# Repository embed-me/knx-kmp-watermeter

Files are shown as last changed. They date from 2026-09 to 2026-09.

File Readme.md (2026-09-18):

# KNX KMP Watermeter



KNX TP1 interface for Kamstrup water/heat meters via the KMP (Kamstrup Meter Protocol). Reads meter data (volume, flow, temperature, battery life) and exposes it on the KNX bus.

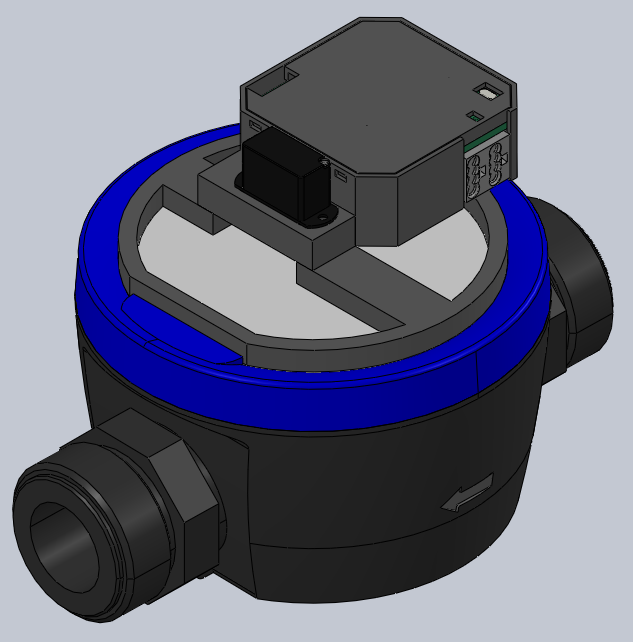
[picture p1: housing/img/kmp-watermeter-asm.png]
KMP Watermeter assembly


## Overview

The device is built around an RP2040 (Raspberry Pi Pico) coupled to the KNX bus via an NCN5130-based BCU. It polls the meter over its optical interface using the KMP protocol and publishes the readings as KNX group objects: 

- **Volume** (m³)
- **Flow** (l/h)
- **Temperature** (°C)
- **Battery life** (days)

Registers can be enabled/disabled individually and polled on a configurable crontab-style schedule.

## Project Structure

| Directory | Description | Documentation |
|---|---|---|
| `firmware/` | RP2040 firmware (PlatformIO, C++) | [Readme.md](firmware/Readme.md) |
| `hardware/` | PCB design (Altium Designer) | [Readme.md](hardware/Readme.md) |
| `housing/` | 3D-printable enclosure (SOLIDWORKS) | [Readme.md](housing/Readme.md) |
| `software/` | KNX ETS product database source | [Readme.md](software/Readme.md) |

## Firmware

Custom firmware for the RP2040 that implements the KMP protocol stack over UART to communicate with Kamstrup Multical 601/801 meters. Data is published via the KNX TP1 bus using the thelsing/knx library with an NCN5130-based BCU. Meters are polled via a servo-actuated wake-up mechanism.

See [firmware/Readme.md](firmware/Readme.md) for build, flash, and test instructions.

## Hardware

Custom 2-layer PCB combining an RP2040 MCU with an NCN5130 BCU (NanoBCU-based) for KNX TP1 bus coupling. Includes a servo driver for meter wake-up and an IR optical transceiver for KMP communication.

See [hardware/Readme.md](hardware/Readme.md) for the project structure and production package.

## Housing

Flush-mount 3D-printable enclosure consisting of four printed parts, designed for standard installation boxes.

See [housing/Readme.md](housing/Readme.md) for the model files and ready-to-print STL exports.

## ETS Configuration

KNX product database for ETS (tested with ETS 6.6). The device exposes group objects for volume, flow, temperature, and battery life, with configurable polling intervals and per-register enable/disable.

See [software/Readme.md](software/Readme.md) for group objects, parameters, and regeneration instructions.

## License

MIT — see [LICENSE](LICENSE).

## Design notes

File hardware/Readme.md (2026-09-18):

# Hardware — KMP Watermeter PCB

PCB combining an RP2040 MCU (Raspberry Pi Pico) with an NCN5130 BCU (NanoBCU-based) for KNX TP1 bus coupling. It uses a servo driver for water meter wake-up, driving a NEEBRC 2g Micro Servo.

The board is designed as a 2-layer PCB in Altium Designer.

The NanoBCU and the UP board are available from [muster.ing-dom.de](https://muster.ing-dom.de/).

## Project Structure

| Directory | Contents |
|---|---|
| [project/](project/) | Altium Designer project: schematic (3 sheets), PCB, BOM, and custom component libraries |
| [production_package/](production_package/) | Ready-to-order Gerber files and drill data |
| [Design Rules/](Design%20Rules/) | JLCPCB design rule files (2-layer, 1 oz / 2 oz copper) |

The schematic is split into three sheets: the main sheet (MCU sockets, servo header, power supply), plus dedicated [Transmitter](project/Transmitter.SchDoc) and [Receiver](project/Receiver.SchDoc) sheets for the IR optical transceiver used for KMP communication.

## Production Package

Ready-to-order PCB files are available in the [production package](production_package/).

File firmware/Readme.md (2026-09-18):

# KNX KMP Watermeter — Firmware

RP2040 firmware implementing the Kamstrup Meter Protocol (KMP) over UART to read data from Kamstrup Multical 601/801 water/heat meters and publish it on the KNX TP1 bus.

## Setup

```bash
pip install platformio
```

## Build

```bash
pio run -e release
```

Flash `.pio/build/release/firmware.uf2` via UF2 bootloader (hold BOOTSEL, press RESET, copy UF2 to mounted drive).

## Unit Tests

```bash
pio test -e test
```

## Static Code Analysis

```bash
sudo apt-get install -y cppcheck
pio check -e check
```

## Protocol Reference

- [Kamstrup.md](Kamstrup.md) — KMP protocol description (extracted from Kamstrup document 5512-447)

## Architecture

The firmware implements a layered KMP protocol stack:

| Layer | Responsibility |
|---|---|
| `PhysicalLayer` | UART framing, byte-stuffing, start/stop detection |
| `DataLinkLayer` | Destination addressing, CRC-16/CCITT verification |
| `ApplicationLayer` | Command dispatch (GetSerialNo, GetRegister), response routing |

Devices polled via servo-actuated wake-up mechanism. See `src/application/WatermeterApp.cpp` for the main polling loop.

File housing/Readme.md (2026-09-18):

# Housing — KMP Watermeter Enclosure

3D-printable housing for the KMP Watermeter - designed to be robust and compact.

## Assembly

The animation below shows how the individual parts come together into the final assembly:

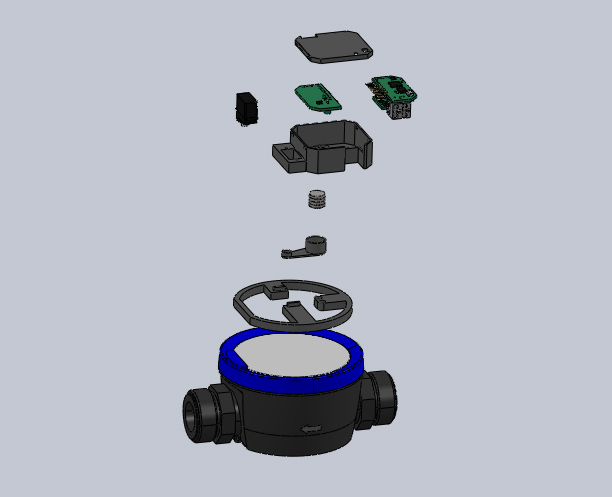
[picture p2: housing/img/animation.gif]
Housing assembly animation


## Model

The housing is modeled in SOLIDWORKS and consists of four parts:

| Part | File |
|---|---|
| Housing | [Housing.SLDPRT](parts/Housing.SLDPRT) |
| Cover | [Cover.SLDPRT](parts/Cover.SLDPRT) |
| Servo Arm | [Servo Arm.SLDPRT](parts/Servo%20Arm.SLDPRT) |
| Fixture | [Fixture.SLDPRT](parts/Fixture.SLDPRT) |

The part files are available in the [parts](parts/) directory. The complete assembly combining all parts and PCBs is available in the [assembly](assembly/) directory.

The Servo Arm is designed for the [NEEBRC 2g Micro Servo](https://de.aliexpress.com/item/1005010177333036.html), which actuates the water meter wake-up mechanism.

## Exported STL Files for Printing

If you'd like to print the housing as-is, the ready-to-use STL files are available in the [print_package](print_package/) directory.

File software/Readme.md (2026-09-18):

# Software — KNX ETS Product Database

ETS product database for the KNX KMP Watermeter, tested with **ETS 6.6**.

## Quick Start

If you do not need to modify the product database, simply load the [existing product database](productdatabase/) into ETS and use it as any other vendor product.

## Group Objects

| No. | Name | Function | DPT |
|-----|---|---|-----|
| 1 | Linked | Connection state to the meter, updated on every poll | DPT_State |
| 2 | Flow | Current water flow | DPT_Value_Volume_Flow |
| 3 | Volume | Total volume | DPT_Value_Volume |
| 4 | Temperature | Water temperature | DPT_Value_Temp |
| 5 | Battery Life | Remaining battery life in days | DPT_Value_2_Ucount |
| 6 | Time | Device RTC time sync input | DPT_Time (10.001) |
| 7 | Date | Device RTC date sync input | DPT_Date (11.001) |

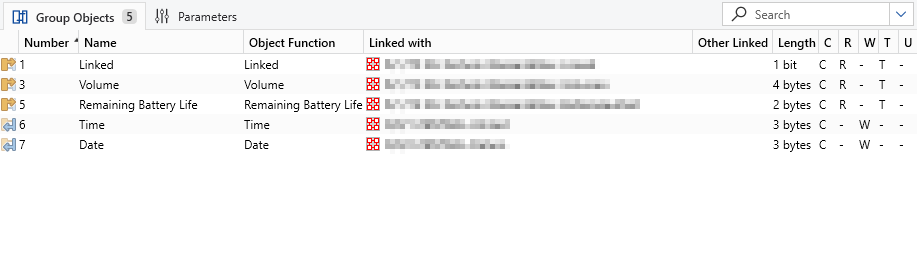
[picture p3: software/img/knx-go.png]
Group objects in ETS


## ETS Parameters

| Parameter | Type | Description |
|---|---|---|
| Polling Interval | Text (16 chars) | Crontab-style schedule for register polling (see below) |
| Volume | 1-bit | Enable/disable volume register read |
| Flow | 1-bit | Enable/disable flow register read |
| Temperature | 1-bit | Enable/disable temperature register read |
| Battery Life | 1-bit | Enable/disable battery life register read |

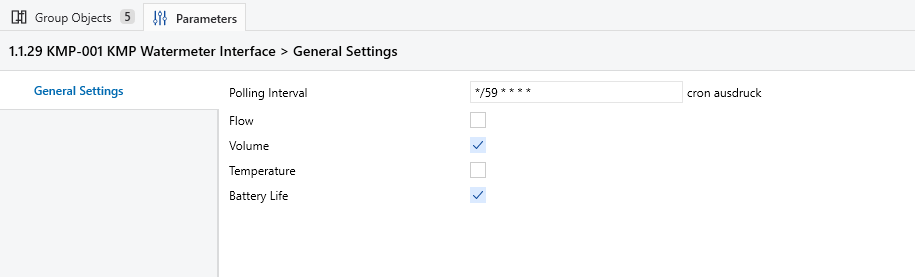
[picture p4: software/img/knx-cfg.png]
ETS parameters


### Polling Interval Format

Standard crontab syntax with five fields: minute (0–59), hour (0–23), day of month (1–31), month (1–12), day of week (1–7, Sunday = 7). Each field supports `*`, step values (`*/15`), ranges (`9-17`), and comma-separated lists (`5,10,15`).

Examples:
- `*/15 * * * *` — every 15 minutes
- `0 9-17 * * 1-5` — hourly between 9:00 and 17:00 on weekdays

The schedule is evaluated against the device RTC, which is synchronized via the Time (6) and Date (7) group objects.

## KMP Registers Polled

| Register ID | Name | Unit |
|---|---|---|
| `0x0044` | Volume | m³/l |
| `0x004A` | Flow | l/h |
| `0x0124` | Temperature | °C |
| `0x0246` | Battery Life | days |

## Tools

The product database is created with **[Kaenx-Creator](https://github.com/OpenKNX/Kaenx-Creator)**.

### Recommended Version

Kaenx-Creator is under active development. Use **[v1.8.4](https://github.com/OpenKNX/Kaenx-Creator/tree/v1.8.4)** for compatibility.

- **Binary Download**: [Kaenx Creator v1.8.4](https://github.com/OpenKNX/Kaenx-Creator/releases/download/v1.8.4/Kaenx.Creator.Binaries.zip)
- **MD5 Hash**: `9aeb971f7844eeafb54341031f3e4ef8`

## Regeneration

To modify or recreate the product database:

1. Open `kmp-watermeter.ae-manu` in Kaenx-Creator.
2. Make changes and increase the version number.
3. Re-deploy the database.

Generated outputs include:

- **`knxprod.h`** — Move this file to `firmware/src/drivers/knx/data/`.

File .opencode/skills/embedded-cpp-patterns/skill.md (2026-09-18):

# Embedded C++ Patterns (SOLID & DRY)

Guidelines for embedded firmware design applied in this repo.

## SOLID in practice

| Principle | Application in this repo |
|---|---|
| **S**ingle Responsibility | Each class does one thing: `CommandQueue` queues commands, `CRC` computes checksums, `PhysicalLayer` handles UART framing |
| **O**pen/Closed | Interfaces (`IKnxDriver`, `IGpioDriver`, `ITimer`) are open for extension via new implementations, closed for modification |
| **L**iskov Substitution | All interface implementations are substitutable — `ArduinoTimer` can be swapped with `MockTimer` in tests |
| **I**nterface Segregation | `IDriverFactory` is composed of small segregated interfaces (`IGpioDriverFactory`, `IKnxDriverFactory`, etc.) |
| **D**ependency Inversion | High-level code (`WatermeterApp`) depends on abstractions (`IApplicationLayer`, `ITimer`), not concretions |

## OOP Principles

| Principle | Application |
|---|---|
| **Encapsulation** | Each driver interface (`IGpioDriver`, `ITimer`) hides platform internals behind a clean API. State and config are private; only the interface is exposed. |
| **Polymorphism** | Interfaces enable multiple implementations — `ArduinoTimer` (real hardware) and `MockTimer` (test) both implement `ITimer`. |
| **Inheritance** | Class hierarchies follow interface contracts. `ArduinoGpioDriver : IGpioDriver`, `ArduinoLogger : ILogger`. Interfaces are pure virtual with `= 0`. |
| **Composition > Inheritance** | `WatermeterApp` *has-a* `CommandQueue`, *has-a* `ITimer`, *has-a* `IApplicationLayer`. Favor composing small interfaces over deep class hierarchies. |

## DRY — Don't Repeat Yourself

- Factor hardware platform code behind interfaces in `firmware/src/drivers/`
- Reuse `CommandQueue`, `CRC`, `ByteStuff` across commands and layers
- If you write the same logic twice, extract it into `firmware/src/utils/`

## Embedded-specific patterns

| Pattern | Where | Why |
|---|---|---|
| **Interface + Impl** | `drivers/*/I*.hpp` + `arduino/*.cpp` | Decouple from Arduino/Pico SDK; enables native testing |
| **Dependency Injection** | Constructor args (e.g. `WatermeterWakeupDriver(motion, cfg, timer)`) | Testable without hardware |
| **RAII** | `shared_ptr` ownership throughout | Automatic cleanup on resource-constrained MCU |
| **Factory** | `ArduinoDriverFactory`, `ArduinoTimerFactory` | Centralized creation of platform-specific objects |
| **Strategy** | `ISchedulerStrategy` / `SimpleScheduler` | Pluggable scheduling behavior |
| **Layered Protocol** | `PhysicalLayer` → `DataLinkLayer` → `ApplicationLayer` | OSI-inspired separation of concerns |
| **Observer** | Listener callbacks in transport layers | Decouple senders from receivers |

## Code style rules

1. Pure virtual interfaces get `I` prefix: `ITimer`, `IGpioDriver`
2. Config structs are plain `struct`s with aggregate init
3. No exceptions (RTTI only for KNX stack); errors flow through `CommandResult`
4. Avoid dynamic allocation in hot paths; pre-allocate in `setup()`
5. Logging is disabled in release (`-DKNX_KMP_WATERMETER_DISABLE_LOGGING`)

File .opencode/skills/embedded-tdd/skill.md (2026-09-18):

# Embedded TDD (Red-Green-Refactor)

Test-Driven Development for embedded C++ firmware using GoogleTest on native host.

## Workflow

### 1. RED — Write a failing test first
- Add a new test suite under `firmware/test/test_<component>/`
- Each suite needs a `test_main.cpp` and `test_<component>.cpp`
- Include the unit-under-test's `.cpp` directly (native compilation needs it)
- Use `TEST()` or `TEST_F()` from GoogleTest

```cpp
// test/test_foo/test_foo.cpp
#include <gtest/gtest.h>
#include "src/path/to/Foo.cpp"

TEST(FooTest, DoesThing) {
    Foo foo;
    EXPECT_EQ(foo.doThing(), expected);
}
```

### 2. GREEN — Make it compile and pass
- Implement the minimum code in the production source
- For hardware dependencies, use mocks from `test/mocks/`:
  ```cpp
  auto mockTimer = std::make_shared<MockTimer>();
  auto driver = WatermeterWakeupDriver(motion, cfg, mockTimer);
  ```
- For hardware headers unavailable on host, use stubs in `test/stubs/`
- Run: `pio test -e test`

### 3. REFACTOR — Clean up while keeping green
- Apply SOLID and OOP principles, remove duplication, rename for clarity
- Do NOT change behavior
- Re-run tests to confirm

## Test infrastructure conventions

| Resource | Location | Purpose |
|---|---|---|
| Tests | `firmware/test/test_*/` | One directory per component |
| Mocks | `firmware/test/mocks/` | Hand-rolled mock classes (no mocking framework) |
| Stubs | `firmware/test/stubs/` | Platform headers unavailable on host (e.g. `pico/time.h`) |
| Main | `firmware/test/test_*/test_main.cpp` | GoogleTest entry point (`RUN_ALL_TESTS`) |

## Writing mocks

Follow the existing pattern in `test/mocks/`:

```cpp
struct MockFoo : public IFoo {
    bool doThingCalled = false;
    int doThingResult = 42;

    int doThing() override {
        doThingCalled = true;
        return doThingResult;
    }
};
```

Build commands are in [firmware/Readme.md](../../../firmware/Readme.md).

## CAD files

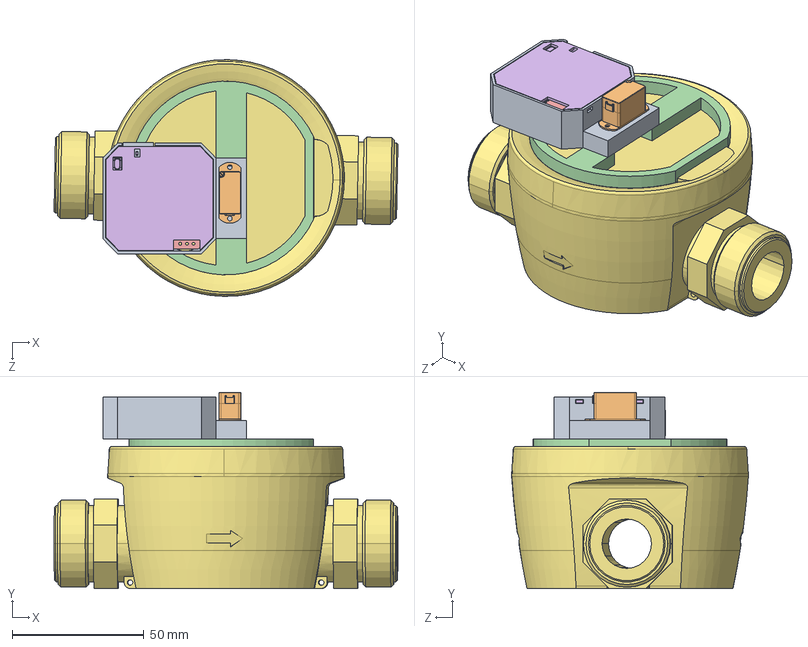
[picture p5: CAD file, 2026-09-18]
housing/assembly/Watermeter-ASM.SLDASM
130.5 x 74.5 x 89.8 mm
Housing
Servo Motor Mini 2g
Servo Arm
Fixture
Leader^6685220592_Q1_PCB KMP-Watermeter_Watermeter-ASM x 3
Extruded^6472411584_R7_PCB KMP-Watermeter_Watermeter-ASM
Extruded-0^6472401024_R7_PCB KMP-Watermeter_Watermeter-ASM x 2
Extruded^6472411584_R8_PCB KMP-Watermeter_Watermeter-ASM
Extruded-0^6472401024_R8_PCB KMP-Watermeter_Watermeter-ASM x 2
Extruded^6472411584_R6_PCB KMP-Watermeter_Watermeter-ASM
Extruded-0^6472401024_R6_PCB KMP-Watermeter_Watermeter-ASM x 2
Extruded-1^6472403024_C3_PCB KMP-Watermeter_Watermeter-ASM x 2
Extruded-2^6472401344_C3_PCB KMP-Watermeter_Watermeter-ASM
6488013344^LED-RX-1_PCB KMP-Watermeter_Watermeter-ASM
6488013344^LED-TX-1_PCB KMP-Watermeter_Watermeter-ASM
Extruded^6472411584_R5_PCB KMP-Watermeter_Watermeter-ASM
Extruded-0^6472401024_R5_PCB KMP-Watermeter_Watermeter-ASM x 2
Extruded^6472411584_R1_PCB KMP-Watermeter_Watermeter-ASM
Extruded-0^6472401024_R1_PCB KMP-Watermeter_Watermeter-ASM x 2
Extruded^6472411584_R2_PCB KMP-Watermeter_Watermeter-ASM
Extruded-0^6472401024_R2_PCB KMP-Watermeter_Watermeter-ASM x 2
Extruded^6472411584_R3_PCB KMP-Watermeter_Watermeter-ASM
Extruded-0^6472401024_R3_PCB KMP-Watermeter_Watermeter-ASM x 2
Extruded^6472411584_R4_PCB KMP-Watermeter_Watermeter-ASM
Extruded-0^6472401024_R4_PCB KMP-Watermeter_Watermeter-ASM x 2
Extruded-3^6472401664_C1_PCB KMP-Watermeter_Watermeter-ASM x 2
Extruded-4^6472401184_C1_PCB KMP-Watermeter_Watermeter-ASM
Extruded-3^6472401664_C2_PCB KMP-Watermeter_Watermeter-ASM x 2
Extruded-4^6472401184_C2_PCB KMP-Watermeter_Watermeter-ASM
pinheader_20pin_127mm_pitch^P1_PCB KMP-Watermeter_Watermeter-ASM
Copy of Pcb_d6bd^PCB UP1-Controller2040_V00.02
Copy of Copy of J102_PinHeader_1x20_P127mm_Horizontal_60EE9F63^PCB UP1-Controller2040_V00.02
Copy of R111_R_0603_1608Metric_6205EFC4^PCB UP1-Controller2040_V00.02
Copy of R112_R_0603_1608Metric_6205EFD5^PCB UP1-Controller2040_V00.02
Copy of GN100_NanoBCU_V00.10_wo_headers_60EECF29^PCB UP1-Controller2040_V00.02
Copy of GN100_PinHeader_1x07_P254mm_Vertical_SMD_Pin1Left_60EECF29[2]^PCB UP1-Controller2040_V00.02
Copy of U102_SOT_23_5_6205ACC4^PCB UP1-Controller2040_V00.02
Copy of U103_SOT_23_6_6205A775^PCB UP1-Controller2040_V00.02
Copy of J100__243-212_60AF9738^PCB UP1-Controller2040_V00.02
Copy of R114_R_0603_1608Metric_61113DD2^PCB UP1-Controller2040_V00.02
Copy of R113_R_0603_1608Metric_61113DC1^PCB UP1-Controller2040_V00.02
Copy of D100_D_SMA_60EECA5D^PCB UP1-Controller2040_V00.02
Copy of J101_PinHeader_1x08_P127mm_Vertical_60ECF3C0^PCB UP1-Controller2040_V00.02
Copy of R109_R_0603_1608Metric_60F57743^PCB UP1-Controller2040_V00.02
Copy of R110_R_0603_1608Metric_60F57732^PCB UP1-Controller2040_V00.02
Copy of R106_R_0402_1005Metric_60F519DA^PCB UP1-Controller2040_V00.02
Copy of U100_QFN-56-1EP_7x7mm_Pitch0.4mm_60ECE89B^PCB UP1-Controller2040_V00.02
Copy of R115_R_0603_1608Metric_60ECF916^PCB UP1-Controller2040_V00.02
Copy of R116_R_0603_1608Metric_60B1282C^PCB UP1-Controller2040_V00.02
Copy of U101_SSOP_8_525x524mm_P127mm_60EDBF3D^PCB UP1-Controller2040_V00.02
Copy of Y100_Crystal_SMD_3225-4Pin_3.2x2.5mm_60EEB131^PCB UP1-Controller2040_V00.02
Copy of SW100_SKRPACE010_v4_60ED873A^PCB UP1-Controller2040_V00.02
Copy of R105_C_0402_1005Metric_60ECE7EE^PCB UP1-Controller2040_V00.02
Copy of R108_C_0402_1005Metric_60ECE7DF^PCB UP1-Controller2040_V00.02
Copy of R107_C_0402_1005Metric_60ECE7D0^PCB UP1-Controller2040_V00.02
Copy of R102_C_0402_1005Metric_60ECE7C1^PCB UP1-Controller2040_V00.02
Copy of R103_C_0402_1005Metric_60ECE7B2^PCB UP1-Controller2040_V00.02
Copy of R104_C_0402_1005Metric_60ECE7A3^PCB UP1-Controller2040_V00.02
Copy of R101_R_0402_1005Metric_60ECE794^PCB UP1-Controller2040_V00.02
Copy of D101_LED_0603_1608Metric_60EEBCB9^PCB UP1-Controller2040_V00.02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

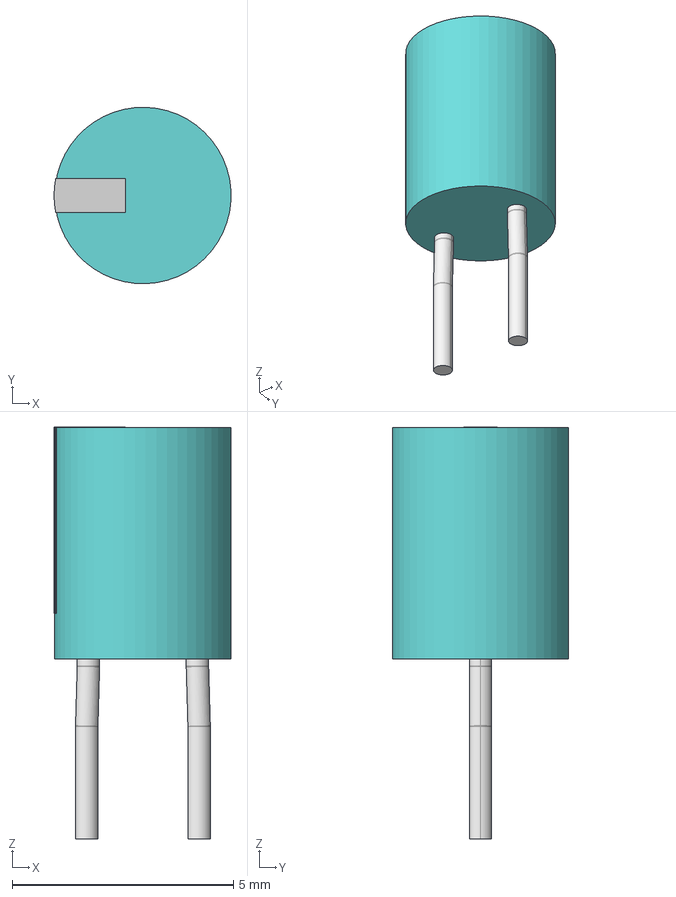
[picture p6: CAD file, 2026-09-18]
hardware/project/Components/HIR204C/LED_RADIAL_HIR204C.step
4.00 x 3.99 x 9.31 mm

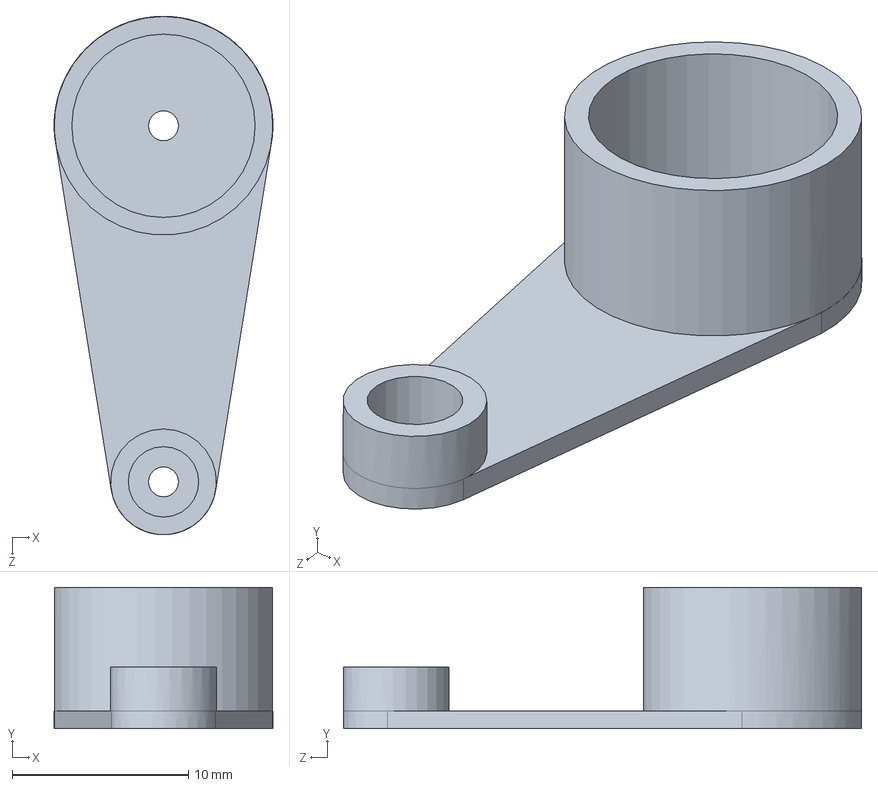
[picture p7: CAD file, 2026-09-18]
housing/parts/Servo Arm.SLDPRT
12.4 x 8.00 x 29.4 mm

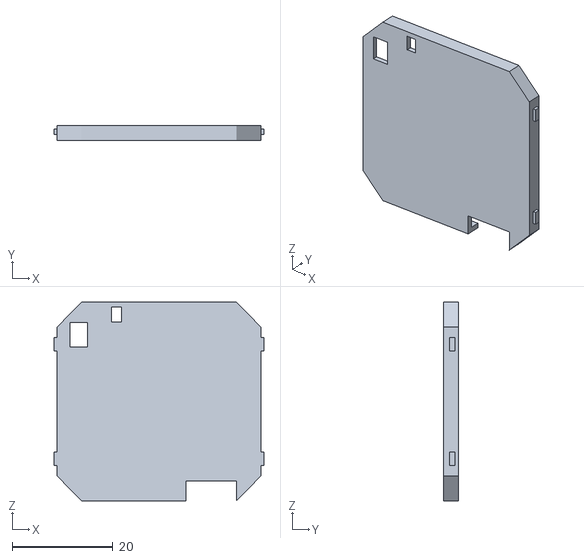
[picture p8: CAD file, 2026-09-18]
housing/print_package/Cover.STL
41.7 x 3.00 x 39.5

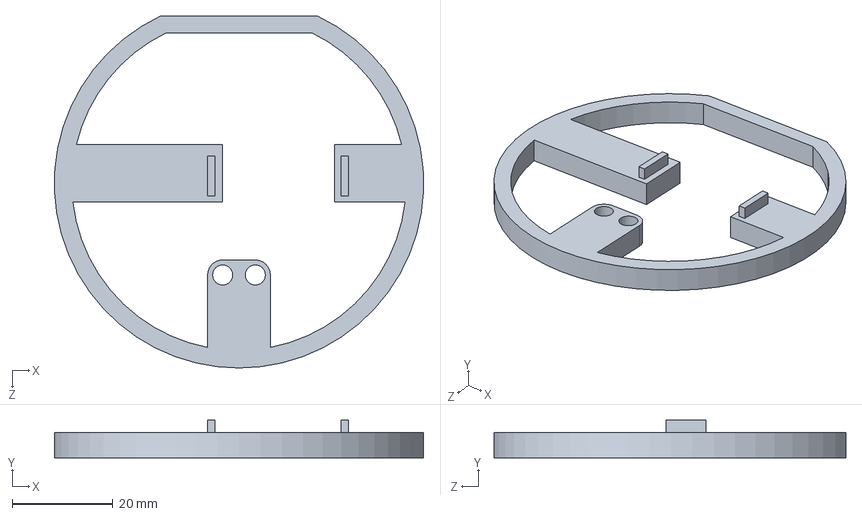
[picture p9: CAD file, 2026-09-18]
housing/parts/Fixture.SLDPRT
73.4 x 7.50 x 70.0 mm

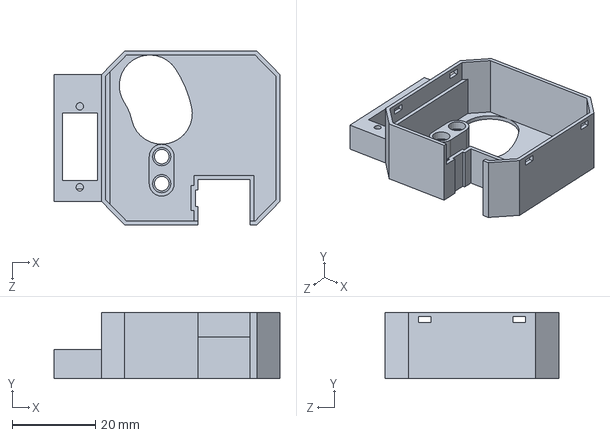
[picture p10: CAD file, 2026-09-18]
housing/parts/Housing.SLDPRT
54.5 x 16.0 x 42.0 mm

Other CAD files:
housing/print_package/Fixture.STL
housing/print_package/Servo Arm.STL
housing/parts/Cover.SLDPRT
housing/print_package/Housing.STL

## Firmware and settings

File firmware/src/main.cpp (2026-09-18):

#include <memory>

#include "drivers/ArduinoDriverFactory.hpp"
#include "drivers/motion/MotionConfig.hpp"

#include "drivers/logger/Logger.hpp"
#include "drivers/logger/ILogger.hpp"

#include "drivers/gpio/IGpioDriver.hpp"

#include "drivers/knx/IKnxDriver.hpp"

#include "drivers/watchdog/IWatchdogDriver.hpp"

#include "drivers/uart/IUartDriver.hpp"

#include "drivers/watermeter/kamstrup/utils/CommandQueueConfig.hpp"

#include "utils/scheduler/Scheduler.hpp"
#include "utils/scheduler/strategy/ISchedulerStrategy.hpp"
#include "utils/scheduler/strategy/simple/SimpleScheduler.hpp"

#include "application/WatermeterApp.hpp"

/* GPIOs */
struct drivers::gpio::GpioConfig knxProgButton = {
    .pin = 7,
    .sensitivity = drivers::gpio::GPIO_SENSITIVITY::INTERRUPT_CHANGE,
    .direction = drivers::gpio::GPIO_DIRECTION::DIRECTION_INPUT,
    .pull = drivers::gpio::GPIO_PULL::PULL_HIGH
};

struct drivers::gpio::GpioConfig knxProgLed = {
    .pin = 6,
    .sensitivity = drivers::gpio::GPIO_SENSITIVITY::ACTIVE_HIGH,
    .direction = drivers::gpio::GPIO_DIRECTION::DIRECTION_OUTPUT,
    .pull = drivers::gpio::GPIO_PULL::PULL_NONE
};

struct drivers::uart::UartConfig kmpUartCfg = {
    .baud = 1200,
    .dataBits = 8,
    .parity = 0,
    .stopBits = 2,
    .txPin = 20,
    .rxPin = 21
};

drivers::motion::MotionConfig wakeupMotionCfg = { 
    .pin = 13,
    .minPulseWidth = 500,
    .maxPulseWidth = 2500,
    .wakeupAngle = 114,
    .sleepAngle = 90,
    .settleDelayUs = 5000000
};

drivers::watermeter::kamstrup::transport::CommandQueueConfig kmpQueueCfg = {
    .commandTimeoutUs = 1600000
};

std::shared_ptr<drivers::IDriverFactory> driverFactory =
    std::make_shared<drivers::ArduinoDriverFactory>();
#ifdef KNX_KMP_WATERMETER_DISABLE_LOGGING
    std::shared_ptr<drivers::logger::ILogger> logger = nullptr;
#else
    std::shared_ptr<drivers::logger::ILogger> logger = driverFactory->getLoggerDriver();
#endif
std::shared_ptr<drivers::gpio::IGpioDriver> gpio = driverFactory->getGpioDriver();
std::shared_ptr<drivers::knx::IKnxDriver> knx = driverFactory->getKnxDriver();
std::shared_ptr<drivers::watchdog::IWatchdogDriver> watchdog = driverFactory->getWatchdogDriver();
std::shared_ptr<drivers::uart::IUartDriver> kmpUart = driverFactory->getUartDriver();
std::shared_ptr<drivers::timer::ITimerDriverFactory> timerFactory = driverFactory->getTimerDriverFactory();

/* Utilities */
std::shared_ptr<utils::ISchedulerStrategy> schedulerStrategy = std::make_shared<utils::SimpleScheduler>();
std::shared_ptr<utils::Scheduler> scheduler = std::make_shared<utils::Scheduler>(schedulerStrategy);

#define WDT_TIMEOUT_MS 8000
#define PROG_BTN_PRESS_MIN_MILLIS 50
#define PROG_BTN_PRESS_MAX_MILLIS 500

void buttonPressHandler(void *arg) 
{
    static uint32_t lastEvent = 0;
    static uint32_t lastPressed = 0;

    uint32_t diff = millis() - lastEvent;

    if (diff >= PROG_BTN_PRESS_MIN_MILLIS && diff <= PROG_BTN_PRESS_MAX_MILLIS)
    {
        if (millis() - lastPressed > 200)
        {
            knx->toggleProgMode();
            lastPressed = millis();
        }
    }

    lastEvent = millis();
}

void buttonInterrupt()
{
    utils::Scheduler::schedule(buttonPressHandler);
}

std::shared_ptr<application::WatermeterApp> watermeterApp = nullptr;

/* Core 0 */
void setup() {
    drivers::logger::Logger::setLogger(logger);
    drivers::logger::Logger::getLogger()->init(drivers::logger::LOGLEVEL::LOGLEVEL_TRACE, true);

    if (watchdog->wasRebootedByWatchdog()) {
        logWarning("System rebooted by watchdog");
    }

    watchdog->enable(WDT_TIMEOUT_MS);

    gpio->setConfig(knxProgLed);
    gpio->setConfig(knxProgButton);
    gpio->setupInterruptHandler(knxProgButton, buttonInterrupt);
    knx->setProgmodeChangeCallback([](bool val) {
        gpio->writeValue(knxProgLed, val);
    });

    bool stackConfigured = knx->init();

    if (stackConfigured) {
        std::string version = knx->getApplicationVersion();
        logInfo("Application Version: " + version);

        auto& knxConfig = knx->getKnxConfig();
        watermeterApp = std::make_shared<application::WatermeterApp>();

        auto motion = driverFactory->getMotionDriver();
        motion->setConfig(wakeupMotionCfg);
        auto wakeupDriver = driverFactory->getWatermeterWakeupDriver(motion, wakeupMotionCfg);
        auto rtcDriver = driverFactory->getRtcDriver();

        watermeterApp->init(kmpUart, kmpUartCfg, knxConfig, kmpQueueCfg, wakeupDriver, timerFactory, rtcDriver);
    } else {
        logWarning("KNX Stack initialization failed");
    }
}

void loop() {
    watchdog->feed();
    watermeterApp->process();
    scheduler->process();
    knx->loop();
}

/* Core 1 */
// void setup1() {
// }

// void loop1() {
// }

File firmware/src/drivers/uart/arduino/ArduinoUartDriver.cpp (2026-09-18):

#include "ArduinoUartDriver.hpp"
#include "src/drivers/logger/Logger.hpp"
#include <Arduino.h>
#include <HardwareSerial.h>

using namespace drivers::logger;

namespace drivers::uart {

ArduinoUartDriver::ArduinoUartDriver()
{
}

bool ArduinoUartDriver::init(const UartConfig &config) 
{
    if (config.dataBits < 5 || config.dataBits > 8) {
        logError("ArduinoUartDriver: invalid dataBits %d", config.dataBits);
        return false;
    }

    if (config.stopBits < 1 || config.stopBits > 2) {
        logError("ArduinoUartDriver: invalid stopBits %d", config.stopBits);
        return false;
    }

    if (config.parity > 2) {
        logError("ArduinoUartDriver: invalid parity %d", config.parity);
        return false;
    }

    // Use Arduino Serial2 (UART1) for KMP communication.
    // Serial1 (UART0) is already used by the KNX stack (KNX_SERIAL).
    if (config.txPin >= 0) {
        Serial2.setTX(config.txPin);
    }
    if (config.rxPin >= 0) {
        Serial2.setRX(config.rxPin);
    }

    int serialConfig = SERIAL_8N1;
    if (config.dataBits == 5) {
        serialConfig = (config.parity == 0) ? SERIAL_5N1 : (config.parity == 1) ? SERIAL_5O1 : SERIAL_5E1;
    } else if (config.dataBits == 6) {
        serialConfig = (config.parity == 0) ? SERIAL_6N1 : (config.parity == 1) ? SERIAL_6O1 : SERIAL_6E1;
    } else if (config.dataBits == 7) {
        serialConfig = (config.parity == 0) ? SERIAL_7N1 : (config.parity == 1) ? SERIAL_7O1 : SERIAL_7E1;
    } else if (config.dataBits == 8) {
        if (config.stopBits == 2) {
            serialConfig = (config.parity == 0) ? SERIAL_8N2 : (config.parity == 1) ? SERIAL_8O2 : SERIAL_8E2;
        } else {
            serialConfig = (config.parity == 0) ? SERIAL_8N1 : (config.parity == 1) ? SERIAL_8O1 : SERIAL_8E1;
        }
    }

    Serial2.begin(config.baud, serialConfig);
    logInfo("ArduinoUartDriver: initialized at %d baud (%d data bits, %d stop bits, tx=%d rx=%d)", config.baud, config.dataBits, config.stopBits, config.txPin, config.rxPin);
    return true;
}

int ArduinoUartDriver::write(const std::vector<uint8_t>& data) 
{
    if (data.empty()) {
        return 0;
    }

    for (const auto& b : data) {
        logTrace("transmitting byte 0x%02X", b);
    }
    size_t written = Serial2.write(data.data(), data.size());

    if (written < data.size()) {
        logWarning("ArduinoUartDriver: write incomplete (%u of %u bytes)", (uint16_t)written, (uint16_t)data.size());
    }

    return static_cast<int>(written);
}

int ArduinoUartDriver::read(uint8_t* buffer, size_t len, uint32_t timeoutMs) 
{
    if (!buffer || len == 0) {
        return -1;
    }

    uint32_t start = millis();
    uint16_t bytesRead = 0;

    while (bytesRead < len && (millis() - start) < timeoutMs) {
        if (Serial2.available()) {
            int byte = Serial2.read();
            if (byte >= 0) {
                buffer[bytesRead++] = static_cast<uint8_t>(byte);
            }
        }
    }

    return static_cast<int>(bytesRead);
}

void ArduinoUartDriver::setRxCallback(std::function<void(const std::vector<uint8_t>&)> cb)
{
    rx_callback_ = cb;
}

void ArduinoUartDriver::process()
{
    if (!rx_callback_) {
        return;
    }
    std::vector<uint8_t> chunk;
    while (Serial2.available()) {
        int b = Serial2.read();
        if (b >= 0) {
            chunk.push_back(static_cast<uint8_t>(b));
            logTrace("received byte 0x%02X", b);
        }
    }
    if (!chunk.empty()) {
        rx_callback_(chunk);
    }
}

}

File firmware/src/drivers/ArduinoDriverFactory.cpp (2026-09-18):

#include "ArduinoDriverFactory.hpp"

#include "timer/arduino/ArduinoTimer.hpp"
#include "gpio/arduino/ArduinoGpioDriver.hpp"
#include "logger/arduino/ArduinoLogger.hpp"
#include "knx/arduino/ThelsingKnxDriver.hpp"
#include "watchdog/arduino/ArduinoWatchdogDriver.hpp"
#include "uart/arduino/ArduinoUartDriver.hpp"
#include "motion/arduino/ArduinoMotionDriver.hpp"
#include "watermeter/wakeup/WatermeterWakeupDriver.hpp"

#include "rtc/arduino/ArduinoRtcDriver.hpp"

#include "logger/Logger.hpp"

using namespace drivers;
using namespace drivers::logger;

ArduinoDriverFactory::ArduinoDriverFactory()
{
}

std::shared_ptr<timer::ITimerDriverFactory> ArduinoDriverFactory::getTimerDriverFactory()
{
    logTrace("creating new Timer Factory");
    auto timerFactory = std::make_shared<timer::ArduinoTimerFactory>();
    return timerFactory;
}

std::shared_ptr<gpio::IGpioDriver> ArduinoDriverFactory::getGpioDriver()
{
    logTrace("creating new Gpio Driver");
    auto gpio = std::make_shared<gpio::ArduinoGpioDriver>();
    return gpio;
}

std::shared_ptr<logger::ILogger> ArduinoDriverFactory::getLoggerDriver()
{
    auto logger = std::make_shared<logger::ArduinoLogger>();
    return logger;
}

std::shared_ptr<knx::IKnxDriver> ArduinoDriverFactory::getKnxDriver()
{
    logTrace("creating new Knx Driver");
    auto knx = std::make_shared<knx::ThelsingKnxDriver>();
    return knx;
}

std::shared_ptr<watchdog::IWatchdogDriver> ArduinoDriverFactory::getWatchdogDriver()
{
    logTrace("creating new Watchdog Driver");
    auto watchdog = std::make_shared<watchdog::ArduinoWatchdogDriver>();
    return watchdog;
}

std::shared_ptr<uart::IUartDriver> ArduinoDriverFactory::getUartDriver()
{
    logTrace("creating new UART Driver");
    auto uartDriver = std::make_shared<uart::ArduinoUartDriver>();
    return uartDriver;
}

std::shared_ptr<motion::IMotionDriver> ArduinoDriverFactory::getMotionDriver()
{
    logTrace("creating new Motion Driver");
    auto motion = std::make_shared<motion::ArduinoMotionDriver>();
    return motion;
}

std::shared_ptr<watermeter::wakeup::IWatermeterWakeupDriver> ArduinoDriverFactory::getWatermeterWakeupDriver(
    std::shared_ptr<motion::IMotionDriver> motion,
    const motion::MotionConfig& cfg)
{
    logTrace("creating new WatermeterWakeup Driver");
    auto timerFactory = getTimerDriverFactory();
    auto settleTimer = timerFactory->getTimer();
    auto wakeup = std::make_shared<watermeter::wakeup::WatermeterWakeupDriver>(motion, cfg, settleTimer);
    return wakeup;
}

std::shared_ptr<rtc::IRtcDriver> ArduinoDriverFactory::getRtcDriver()
{
    logTrace("creating new RTC Driver");
    auto rtc = std::make_shared<rtc::ArduinoRtcDriver>();
    return rtc;
}
